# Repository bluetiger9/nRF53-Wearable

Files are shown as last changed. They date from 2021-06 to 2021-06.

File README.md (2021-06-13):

# Ultra-Low Power nRF53 based Health & Activity Monitor

nRF53 Wearable

More details on **Hackster.io**:</br>
https://www.hackster.io/bluetiger9/ultra-low-power-nrf53-based-health-activity-monitor-e023e1

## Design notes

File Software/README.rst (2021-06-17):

Ultra-Low Power nRF53 based Health & Activity Monitor
#########################

Contents:
********
  - nrf5340_cpuapp - Application CPU firmware, based on peripheral_ht
  - nrf5340_cpunet - Network CPU firmware, based on hci_rpmsg

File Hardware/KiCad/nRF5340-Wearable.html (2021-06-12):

# /home/bluetiger/Dev/KiCAD/nRF5340-Wearable/nRF5340-Wearable.sch

Mon 15 Mar 2021 20:10:22 EET

Eeschema 5.1.9-73d0e3b20d~88~ubuntu20.04.1

Component Count:28

Ref | Qnty | Value | Part | Footprint | Description | Vendor
BT1 | 1 | CR2032 | Device:Battery_Cell | Battery:BatteryHolder_MPD_BC2003_1x2032 | Single-cell battery
C1, C2, C3, C4, C5, C6, C7 | 7 | 0.1u | Device:C_Small | Capacitor_SMD:C_0805_2012Metric | Unpolarized capacitor, small symbol
D1 | 1 | LED_Small | Device:LED_Small | LED_SMD:LED_0805_2012Metric | Light emitting diode, small symbol
IC1 | 1 | MAX30102 | Sensor:MAX30102 | OptoDevice:Maxim_OLGA-14_3.3x5.6mm_P0.8mm | Heart Rate Sensor, 14-OLGA
J1 | 1 | Conn_02x05_Odd_Even | Connector_Generic:Conn_02x05_Odd_Even | Connector_PinHeader_1.27mm:PinHeader_2x05_P1.27mm_Vertical | Generic connector, double row, 02x05, odd/even pin numbering scheme (row 1 odd numbers, row 2 even numbers), script generated (kicad-library-utils/schlib/autogen/connector/)
J2 | 1 | SNS_EXT | Connector:Conn_01x05_Female | Connector_PinHeader_2.00mm:PinHeader_1x05_P2.00mm_Vertical_SMD_Pin1Left | Generic connector, single row, 01x05, script generated (kicad-library-utils/schlib/autogen/connector/)
MK1 | 1 | ICS-41350 | nRF5340-Wearable:ICS-41350 | nRF5340-Wearable:MIC_ICS-41350
R1, R2 | 2 | 1k | Device:R_Small | Resistor_SMD:R_0805_2012Metric | Resistor, small symbol
R3 | 1 | 220 | Device:R_Small | Resistor_SMD:R_0805_2012Metric | Resistor, small symbol
SW1 | 1 | SW_Push | Switch:SW_Push | Button_Switch_SMD:SW_SPST_CK_RS282G05A3 | Push button switch, generic, two pins
U1 | 1 | BT40 | nRF5340-Wearable:BT40 | nRF5340-Wearable:BT40
U2 | 1 | MAX30205MTA+ | nRF5340-Wearable:MAX30205MTA+ | nRF5340-Wearable:SON65P300X300X80-9N
U3, U4, U5, U6, U8, U11 | 6 | FPF1107 | Custom-Common:FPF1107 | nRF5340-Wearable:BGA4C40P2X2_84X84X60N
U7 | 1 | MIC5504-1.8YM5 | Regulator_Linear:MIC5504-1.8YM5 | Package_TO_SOT_SMD:SOT-23-5 | 300mA Low-dropout Voltage Regulator, Vout 1.8V, Vin up to 5.5V, SOT-23
U9 | 1 | ICM-42605 | nRF5340-Wearable:ICM-42605 | nRF5340-Wearable:PQFN50P300X250X97-14N
U10 | 1 | LTR-303ALS-01 | Sensor_Optical:LTR-303ALS-01 | OptoDevice:Lite-On_LTR-303ALS-01 | ambient light sensor, i2c interface, 0.01 to 64k lux, 2.4-3.6V

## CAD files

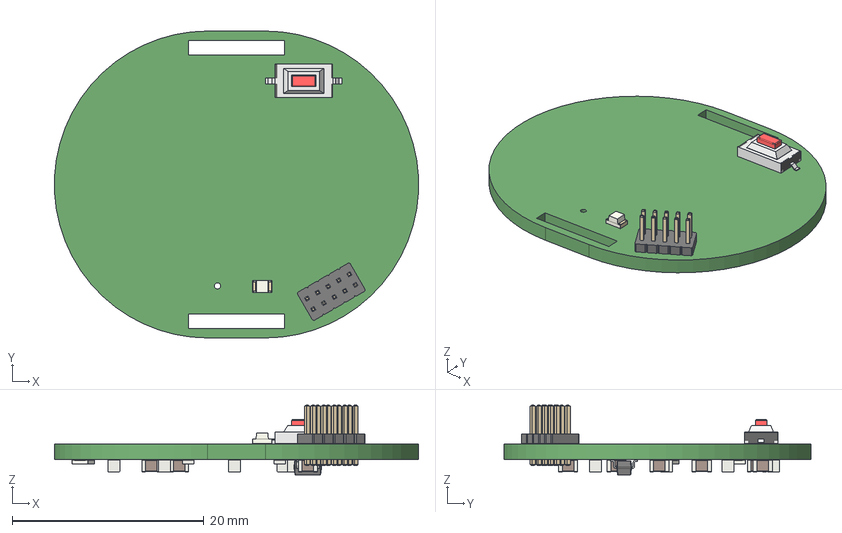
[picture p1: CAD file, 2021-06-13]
3D-Models/nRF5340-Wearable.step
38.0 x 32.0 x 7.25 mm

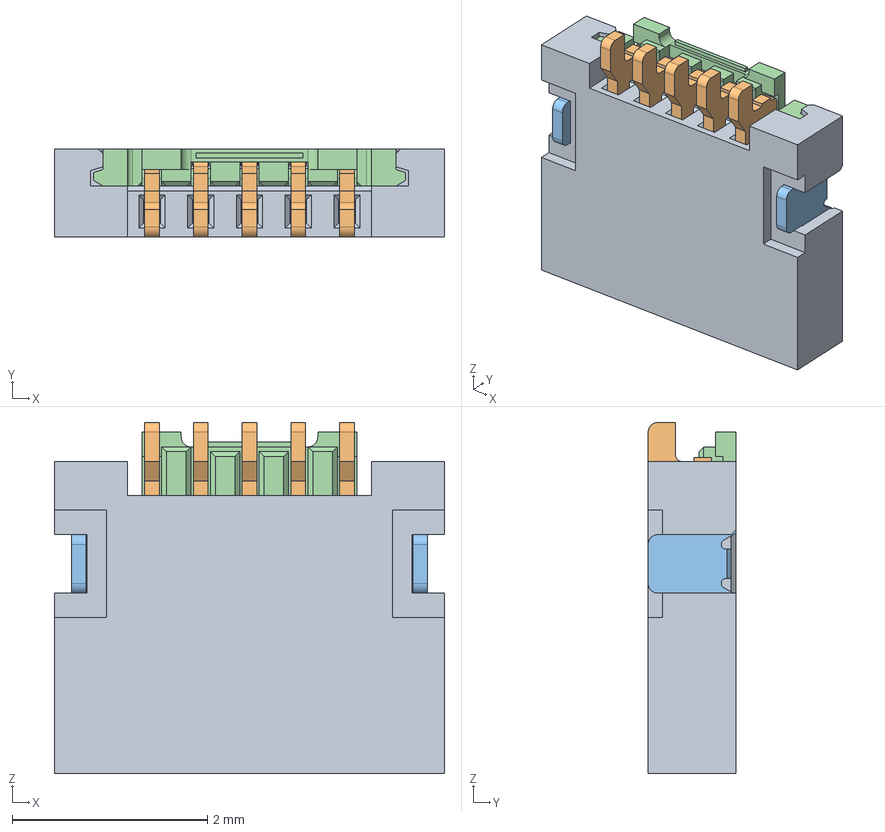
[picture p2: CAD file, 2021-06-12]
Hardware/KiCad/59453-051110echlf.stp
4.00 x 0.9 x 3.60 mm
HSG_D5P
CONTACT_D_S x 5
TAB x 2
ACT_D5P

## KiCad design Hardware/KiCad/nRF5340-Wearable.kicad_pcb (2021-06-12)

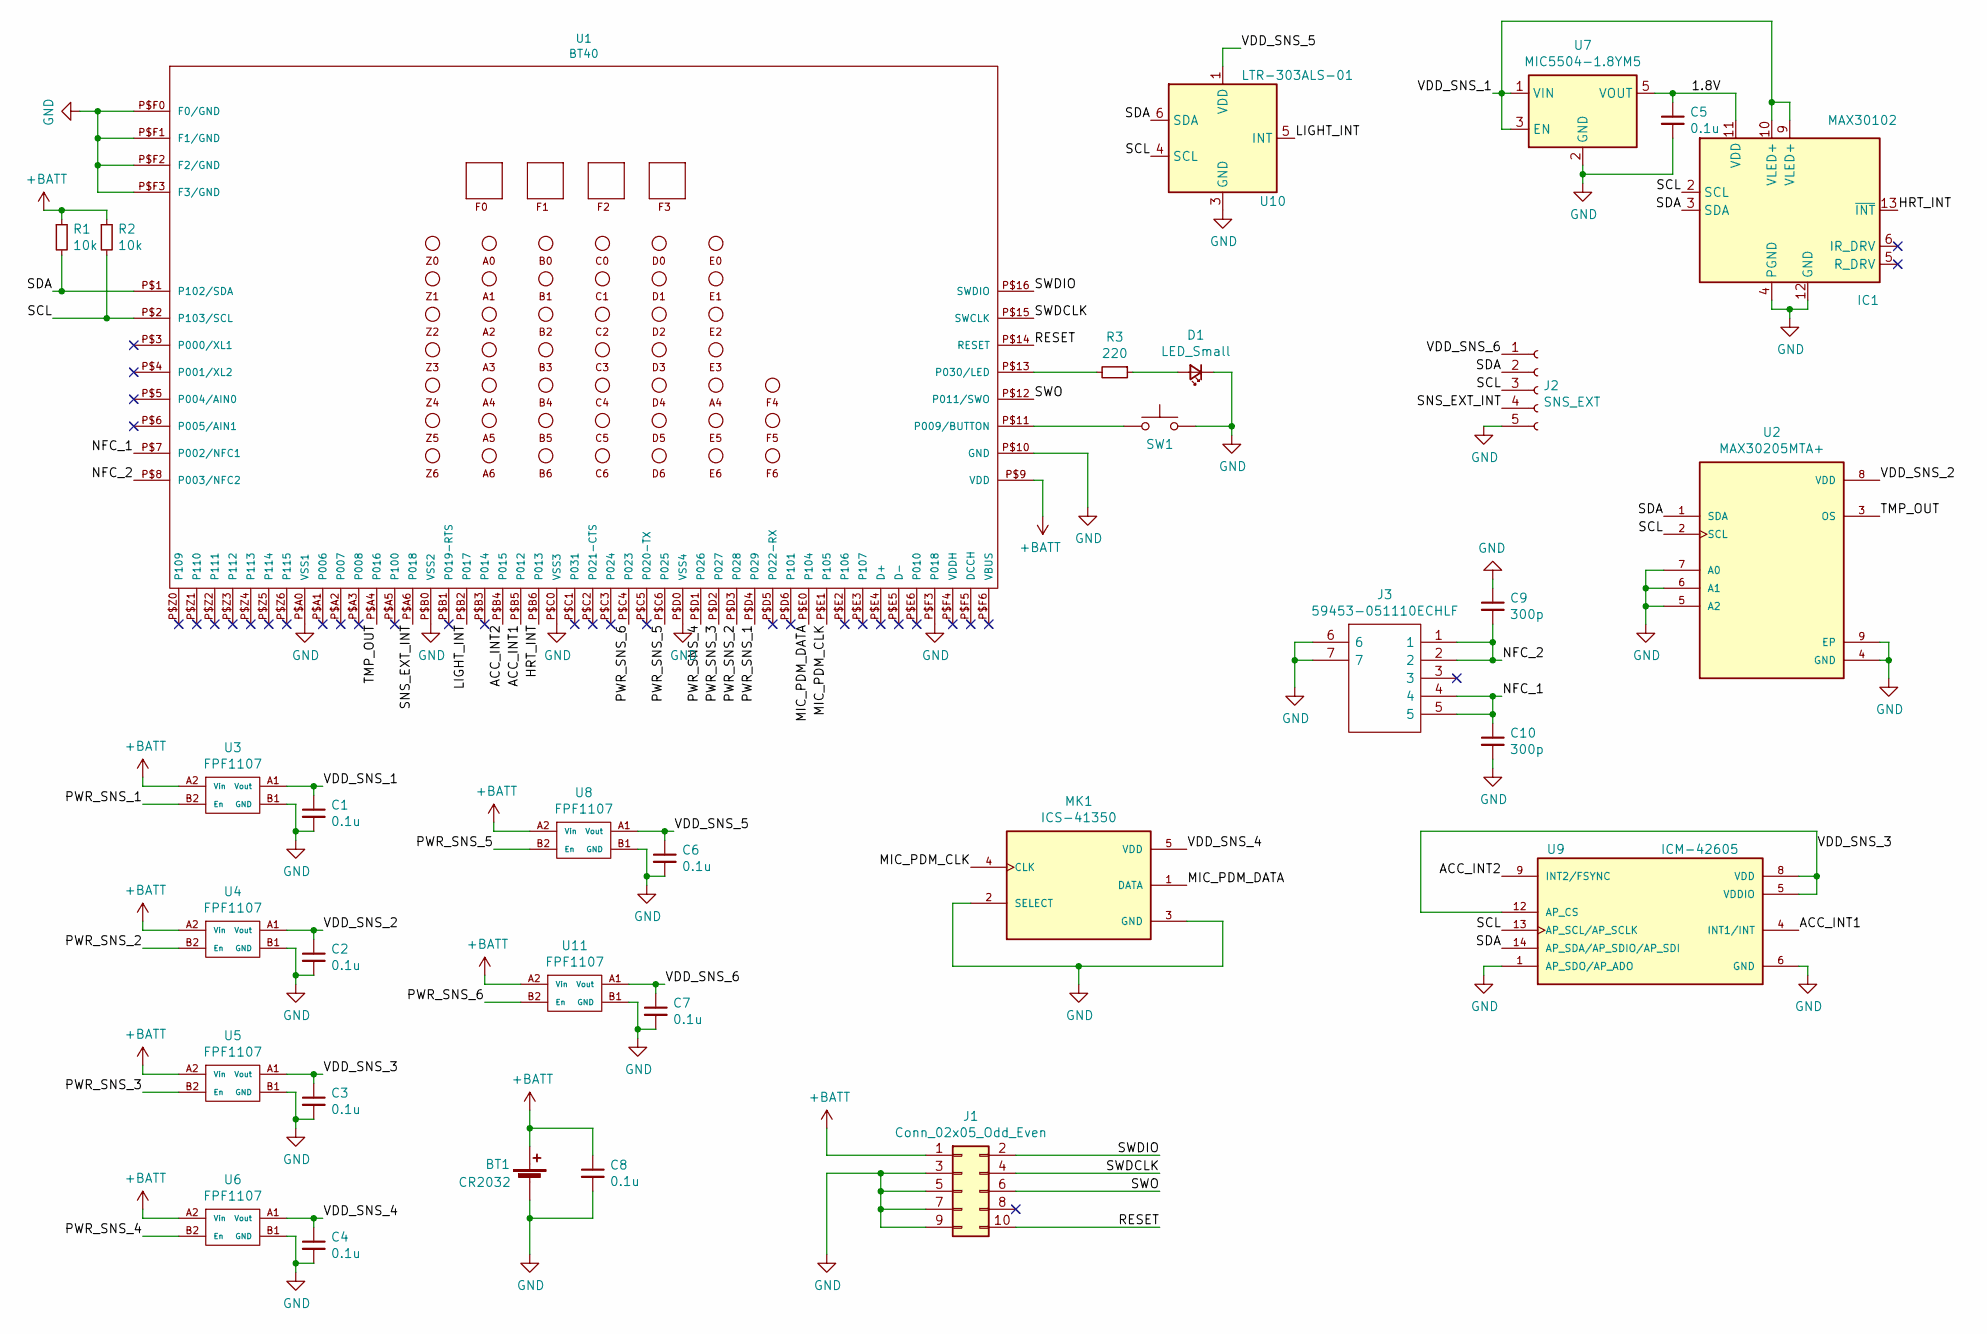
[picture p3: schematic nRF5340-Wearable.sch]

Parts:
BT1: CR2032; BatteryHolder_MPD_BC2003_1x2032
C1, C2, C3, C4, C5, C6, C7, C8: 0.1u; C_0805_2012Metric
C9, C10: 300p; C_0805_2012Metric
D1: LED_Small; LED_0805_2012Metric
IC1: MAX30102; Maxim_OLGA-14_3.3x5.6mm_P0.8mm
J1: Conn_02x05_Odd_Even; PinHeader_2x05_P1.27mm_Vertical
J2: SNS_EXT; PinHeader_1x05_P2.00mm_Vertical_SMD_Pin1Left
J3: 59453-051110ECHLF; 59453051110ECHLF; Manufacturer_Part_Number 59453-051110ECHLF; Mouser Part Number 649-59453051110ECHLF
MK1: ICS-41350; MIC_ICS-41350
R1, R2: 10k; R_0805_2012Metric
R3: 220; R_0805_2012Metric
SW1: SW_Push; SW_SPST_CK_RS282G05A3
U1: BT40
U2: MAX30205MTA+; SON65P300X300X80-9N
U3, U4, U5, U6, U8, U11: FPF1107; BGA4C40P2X2_84X84X60N
U7: MIC5504-1.8YM5; SOT-23-5
U9: ICM-42605; PQFN50P300X250X97-14N; PARTREV 0.4
U10: LTR-303ALS-01; Lite-On_LTR-303ALS-01

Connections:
+BATT: BT1.1 (+), C8.1, J1.1, R1.1, R2.1, U1.P$9 (VDD), U3.A2 (Vin), U4.A2 (Vin), U5.A2 (Vin), U6.A2 (Vin), U8.A2 (Vin), U11.A2 (Vin)
/1.8V: C5.1, IC1.11 (VDD), U7.5 (VOUT)
/ACC_INT1: U1.P$B5 (P012), U9.4 (INT1/INT)
/ACC_INT2: U1.P$B4 (P015), U9.9 (INT2/FSYNC)
/HRT_INT: IC1.13 (~INT), U1.P$B6 (P013)
/LIGHT_INT: U1.P$B2 (P017), U10.5 (INT)
/MIC_PDM_CLK: MK1.4 (CLK), U1.P$E1 (P105)
/MIC_PDM_DATA: MK1.1 (DATA), U1.P$E0 (P104)
/NFC_1: C10.1, J3.4, J3.5, U1.P$7 (P002/NFC1)
/NFC_2: C9.2, J3.1, J3.2, U1.P$8 (P003/NFC2)
/PWR_SNS_1: U1.P$D4 (P029), U3.B2 (En)
/PWR_SNS_2: U1.P$D3 (P028), U4.B2 (En)
/PWR_SNS_3: U1.P$D2 (P027), U5.B2 (En)
/PWR_SNS_4: U1.P$D1 (P026), U6.B2 (En)
/PWR_SNS_5: U1.P$C6 (P025), U8.B2 (En)
/PWR_SNS_6: U1.P$C4 (P023), U11.B2 (En)
/RESET: J1.10, U1.P$14 (RESET)
/SCL: IC1.2 (SCL), J2.3, R2.2, U1.P$2 (P103/SCL), U2.2 (SCL), U9.13 (AP_SCL/AP_SCLK), U10.4 (SCL)
/SDA: IC1.3 (SDA), J2.2, R1.2, U1.P$1 (P102/SDA), U2.1 (SDA), U9.14 (AP_SDA/AP_SDIO/AP_SDI), U10.6 (SDA)
/SNS_EXT_INT: J2.4, U1.P$A6 (P018)
/SWDCLK: J1.4, U1.P$15 (SWCLK)
/SWDIO: J1.2, U1.P$16 (SWDIO)
/SWO: J1.6, U1.P$12 (P011/SWO)
/TMP_OUT: U1.P$A4 (P016), U2.3 (OS)
/VDD_SNS_1: C1.1, IC1.9 (VLED+), IC1.10 (VLED+), U3.A1 (Vout), U7.1 (VIN), U7.3 (EN)
/VDD_SNS_2: C2.1, U2.8 (VDD), U4.A1 (Vout)
/VDD_SNS_3: C3.1, U5.A1 (Vout), U9.5 (VDDIO), U9.8 (VDD), U9.12 (AP_CS)
/VDD_SNS_4: C4.1, MK1.5 (VDD), U6.A1 (Vout)
/VDD_SNS_5: C6.1, U8.A1 (Vout), U10.1 (VDD)
/VDD_SNS_6: C7.1, J2.1, U11.A1 (Vout)
GND: BT1.2 (-), C1.2, C2.2, C3.2, C4.2, C5.2, C6.2, C7.2, C8.2, C9.1, C10.2, D1.1 (K), IC1.4 (PGND), IC1.12 (GND), J1.3, J1.5, J1.7, J1.9, J2.5, J3.6, J3.7, MK1.2 (SELECT), MK1.3 (GND), SW1.2, U1.P$10 (GND), U1.P$A0 (VSS1), U1.P$B0 (VSS2), U1.P$C0 (VSS3), U1.P$D0 (VSS4), U1.P$F0 (F0/GND), U1.P$F1 (F1/GND), U1.P$F2 (F2/GND), U1.P$F3 (F3/GND), U2.4 (GND), U2.5 (A2), U2.6 (A1), U2.7 (A0), U2.9 (EP), U3.B1 (GND), U4.B1 (GND), U5.B1 (GND), U6.B1 (GND), U7.2 (GND), U8.B1 (GND), U9.1 (AP_SDO/AP_ADO), U9.6 (GND), U10.3 (GND), U11.B1 (GND)
unnamed: D1.2 (A), R3.1
unnamed: R3.2, U1.P$13 (P030/LED)
unnamed: SW1.1, U1.P$11 (P009/BUTTON)

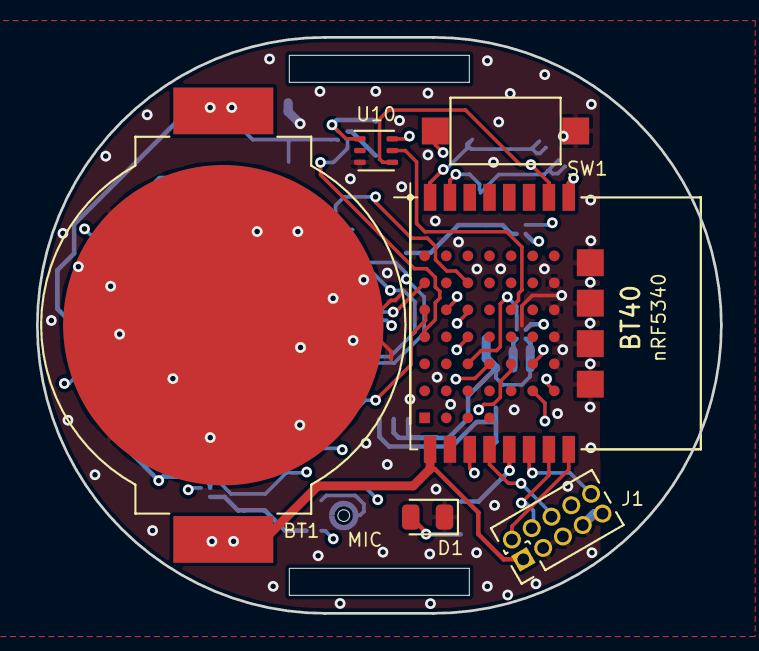
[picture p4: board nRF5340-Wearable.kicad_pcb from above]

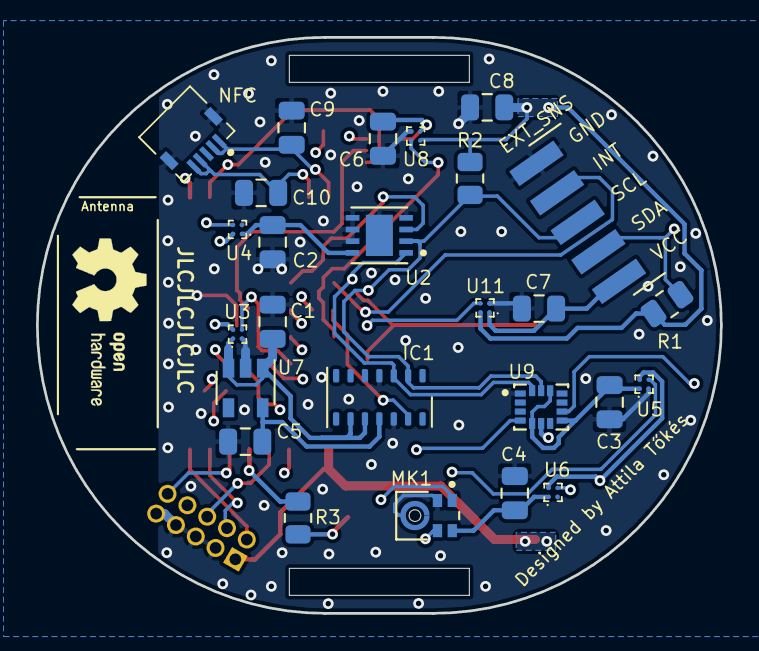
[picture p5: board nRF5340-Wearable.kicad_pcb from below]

Board: 4 copper layers, 38.0 x 32.0 mm, 32 parts (26 on the bottom side), 34 nets.

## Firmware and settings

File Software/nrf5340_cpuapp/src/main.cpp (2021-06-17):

/* main.c - Application main entry point */

/*
 * Copyright (c) 2015-2016 Intel Corporation
 *
 * SPDX-License-Identifier: Apache-2.0
 */

#include <zephyr/types.h>
#include <stddef.h>
#include <string.h>
#include <errno.h>
#include <sys/printk.h>
#include <sys/byteorder.h>
#include <zephyr.h>

#include <bluetooth/bluetooth.h>
#include <bluetooth/hci.h>
#include <bluetooth/conn.h>
#include <bluetooth/uuid.h>
#include <bluetooth/gatt.h>
#include <bluetooth/services/bas.h>
#include <bluetooth/services/hrs.h>

#include <drivers/i2c.h>

#include "main_ble.h"

#include "MAX30105.h"
#include "heartRate.h"
#include "spo2_algorithm.h"

#include "MAX30205.h"

float human_temp = 0;

extern "C" {

float get_heartrate() {
  return human_temp;
}

}
void main(void)
{
	int err;

        const device *i2c_dev;

        i2c_dev = device_get_binding("I2C_1");
        if (i2c_dev == NULL) {
            printk("I2C Init Failed!\n");
            return;
        }

        // I2C Scan
        printk("I2C scan start!\n");
        for (uint8_t addr = 0x02; addr < /*128*/ 0; ++addr) {
          uint8_t cmd = 1;
          int error = i2c_write(i2c_dev, &cmd, 1, addr);
          if (error == 0) {
            printk("I2C device found at addr 0x%2X!\n", addr);
          }
        }
        printk("I2C scan end!\n");

        MAX30205 max30205(i2c_dev);
        if (!max30205.scanAvailableSensors()) {
          printk("MAX30205 not found!\n");
          return;
        }
      
        printk("MAX30205 found!\n");

        max30205.begin();
        max30205.printRegisters();
        
        float temp = max30205.getTemperature();
        printk("\nMAX30102 temp: %d.%2df C!\n", (int) temp, (int) (100.0 * temp) % 100);
        
        // MAX30102 Init
        //MAX30105 max30102;
        //if (!max30102.begin(i2c_dev)) {
        //  printk("MAX30102 init failed!\n");
        //  return;
        //}

        //printk("MAX30102 init OK!\n");

	err = bt_enable(NULL);
	if (err) {
		printk("Bluetooth init failed (err %d)\n", err);
		return;
	}

	bt_ready();

	bt_conn_cb_register(&conn_callbacks);
	bt_conn_auth_cb_register(&auth_cb_display);

	/* Implement notification. At the moment there is no suitable way
	 * of starting delayed work so we do it here
	 */
	while (1) {
		k_sleep(K_SECONDS(1));

		/* Heartrate measurements simulation */
                human_temp = max30205.getTemperature();
		hrs_notify();

		/* Battery level simulation */
		bas_notify();
	}
}

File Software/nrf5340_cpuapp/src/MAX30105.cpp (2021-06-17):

/***************************************************
  This is a library written for the Maxim MAX30105 Optical Smoke Detector
  It should also work with the MAX30102. However, the MAX30102 does not have a Green LED.

  These sensors use I2C to communicate, as well as a single (optional)
  interrupt line that is not currently supported in this driver.

  Written by Peter Jansen and Nathan Seidle (SparkFun)
  BSD license, all text above must be included in any redistribution.
 *****************************************************/

#include "MAX30105.h"
#include <string.h> // memcpy


long millis() {
  return k_uptime_get();
};

void delay(long delayMs) {
  long start = millis();
  while (millis() < delayMs + start);
};


// Status Registers
static const uint8_t MAX30105_INTSTAT1 =		0x00;
static const uint8_t MAX30105_INTSTAT2 =		0x01;
static const uint8_t MAX30105_INTENABLE1 =		0x02;
static const uint8_t MAX30105_INTENABLE2 =		0x03;

// FIFO Registers
static const uint8_t MAX30105_FIFOWRITEPTR = 	0x04;
static const uint8_t MAX30105_FIFOOVERFLOW = 	0x05;
static const uint8_t MAX30105_FIFOREADPTR = 	0x06;
static const uint8_t MAX30105_FIFODATA =		0x07;

// Configuration Registers
static const uint8_t MAX30105_FIFOCONFIG = 		0x08;
static const uint8_t MAX30105_MODECONFIG = 		0x09;
static const uint8_t MAX30105_PARTICLECONFIG = 	0x0A;    // Note, sometimes listed as "SPO2" config in datasheet (pg. 11)
static const uint8_t MAX30105_LED1_PULSEAMP = 	0x0C;
static const uint8_t MAX30105_LED2_PULSEAMP = 	0x0D;
static const uint8_t MAX30105_LED3_PULSEAMP = 	0x0E;
static const uint8_t MAX30105_LED_PROX_AMP = 	0x10;
static const uint8_t MAX30105_MULTILEDCONFIG1 = 0x11;
static const uint8_t MAX30105_MULTILEDCONFIG2 = 0x12;

// Die Temperature Registers
static const uint8_t MAX30105_DIETEMPINT = 		0x1F;
static const uint8_t MAX30105_DIETEMPFRAC = 	0x20;
static const uint8_t MAX30105_DIETEMPCONFIG = 	0x21;

// Proximity Function Registers
static const uint8_t MAX30105_PROXINTTHRESH = 	0x30;

// Part ID Registers
static const uint8_t MAX30105_REVISIONID = 		0xFE;
static const uint8_t MAX30105_PARTID = 			0xFF;    // Should always be 0x15. Identical to MAX30102.

// MAX30105 Commands
// Interrupt configuration (pg 13, 14)
static const uint8_t MAX30105_INT_A_FULL_MASK =		(uint8_t)~0b10000000;
static const uint8_t MAX30105_INT_A_FULL_ENABLE = 	0x80;
static const uint8_t MAX30105_INT_A_FULL_DISABLE = 	0x00;

static const uint8_t MAX30105_INT_DATA_RDY_MASK = (uint8_t)~0b01000000;
static const uint8_t MAX30105_INT_DATA_RDY_ENABLE =	0x40;
static const uint8_t MAX30105_INT_DATA_RDY_DISABLE = 0x00;

static const uint8_t MAX30105_INT_ALC_OVF_MASK = (uint8_t)~0b00100000;
static const uint8_t MAX30105_INT_ALC_OVF_ENABLE = 	0x20;
static const uint8_t MAX30105_INT_ALC_OVF_DISABLE = 0x00;

static const uint8_t MAX30105_INT_PROX_INT_MASK = (uint8_t)~0b00010000;
static const uint8_t MAX30105_INT_PROX_INT_ENABLE = 0x10;
static const uint8_t MAX30105_INT_PROX_INT_DISABLE = 0x00;

static const uint8_t MAX30105_INT_DIE_TEMP_RDY_MASK = (uint8_t)~0b00000010;
static const uint8_t MAX30105_INT_DIE_TEMP_RDY_ENABLE = 0x02;
static const uint8_t MAX30105_INT_DIE_TEMP_RDY_DISABLE = 0x00;

static const uint8_t MAX30105_SAMPLEAVG_MASK =	(uint8_t)~0b11100000;
static const uint8_t MAX30105_SAMPLEAVG_1 = 	0x00;
static const uint8_t MAX30105_SAMPLEAVG_2 = 	0x20;
static const uint8_t MAX30105_SAMPLEAVG_4 = 	0x40;
static const uint8_t MAX30105_SAMPLEAVG_8 = 	0x60;
static const uint8_t MAX30105_SAMPLEAVG_16 = 	0x80;
static const uint8_t MAX30105_SAMPLEAVG_32 = 	0xA0;

static const uint8_t MAX30105_ROLLOVER_MASK = 	0xEF;
static const uint8_t MAX30105_ROLLOVER_ENABLE = 0x10;
static const uint8_t MAX30105_ROLLOVER_DISABLE = 0x00;

static const uint8_t MAX30105_A_FULL_MASK = 	0xF0;

// Mode configuration commands (page 19)
static const uint8_t MAX30105_SHUTDOWN_MASK = 	0x7F;
static const uint8_t MAX30105_SHUTDOWN = 		0x80;
static const uint8_t MAX30105_WAKEUP = 			0x00;

static const uint8_t MAX30105_RESET_MASK = 		0xBF;
static const uint8_t MAX30105_RESET = 			0x40;

static const uint8_t MAX30105_MODE_MASK = 		0xF8;
static const uint8_t MAX30105_MODE_REDONLY = 	0x02;
static const uint8_t MAX30105_MODE_REDIRONLY = 	0x03;
static const uint8_t MAX30105_MODE_MULTILED = 	0x07;

// Particle sensing configuration commands (pgs 19-20)
static const uint8_t MAX30105_ADCRANGE_MASK = 	0x9F;
static const uint8_t MAX30105_ADCRANGE_2048 = 	0x00;
static const uint8_t MAX30105_ADCRANGE_4096 = 	0x20;
static const uint8_t MAX30105_ADCRANGE_8192 = 	0x40;
static const uint8_t MAX30105_ADCRANGE_16384 = 	0x60;

static const uint8_t MAX30105_SAMPLERATE_MASK = 0xE3;
static const uint8_t MAX30105_SAMPLERATE_50 = 	0x00;
static const uint8_t MAX30105_SAMPLERATE_100 = 	0x04;
static const uint8_t MAX30105_SAMPLERATE_200 = 	0x08;
static const uint8_t MAX30105_SAMPLERATE_400 = 	0x0C;
static const uint8_t MAX30105_SAMPLERATE_800 = 	0x10;
static const uint8_t MAX30105_SAMPLERATE_1000 = 0x14;
static const uint8_t MAX30105_SAMPLERATE_1600 = 0x18;
static const uint8_t MAX30105_SAMPLERATE_3200 = 0x1C;

static const uint8_t MAX30105_PULSEWIDTH_MASK = 0xFC;
static const uint8_t MAX30105_PULSEWIDTH_69 = 	0x00;
static const uint8_t MAX30105_PULSEWIDTH_118 = 	0x01;
static const uint8_t MAX30105_PULSEWIDTH_215 = 	0x02;
static const uint8_t MAX30105_PULSEWIDTH_411 = 	0x03;

//Multi-LED Mode configuration (pg 22)
static const uint8_t MAX30105_SLOT1_MASK = 		0xF8;
static const uint8_t MAX30105_SLOT2_MASK = 		0x8F;
static const uint8_t MAX30105_SLOT3_MASK = 		0xF8;
static const uint8_t MAX30105_SLOT4_MASK = 		0x8F;

static const uint8_t SLOT_NONE = 				0x00;
static const uint8_t SLOT_RED_LED = 			0x01;
static const uint8_t SLOT_IR_LED = 				0x02;
static const uint8_t SLOT_GREEN_LED = 			0x03;
static const uint8_t SLOT_NONE_PILOT = 			0x04;
static const uint8_t SLOT_RED_PILOT =			0x05;
static const uint8_t SLOT_IR_PILOT = 			0x06;
static const uint8_t SLOT_GREEN_PILOT = 		0x07;

static const uint8_t MAX_30105_EXPECTEDPARTID = 0x15;

MAX30105::MAX30105() {
  // Constructor
}

bool MAX30105::begin(const device *wirePort, uint8_t i2c_addr) {

  _i2cPort = wirePort; //Grab which port the user wants us to use

  //_i2cPort->begin();
  //_i2cPort->setClock(i2cSpeed);

  _i2caddr = i2c_addr;

  // Step 1: Initial Communication and Verification
  // Check that a MAX30105 is connected
  if (readPartID() != MAX_30105_EXPECTEDPARTID) {
    printk("MAX3010x init failed!\n");
    // Error -- Part ID read from MAX30105 does not match expected part ID.
    // This may mean there is a physical connectivity problem (broken wire, unpowered, etc).
    return false;
  }

  printk("MAX3010x init OK!\n");

  // Populate revision ID
  readRevisionID();
  
  return true;
}

//
// Configuration
//

//Begin Interrupt configuration
uint8_t MAX30105::getINT1(void) {
  return (readRegister8(_i2caddr, MAX30105_INTSTAT1));
}
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

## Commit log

2021-06-12 Add KiCAD project
    [59453-051110echlf.stp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]
2021-06-13 Add 3D Files
    [nRF5340-Wearable.step]
